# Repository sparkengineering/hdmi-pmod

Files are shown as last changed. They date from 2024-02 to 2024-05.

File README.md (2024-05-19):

# hdmi-pmod





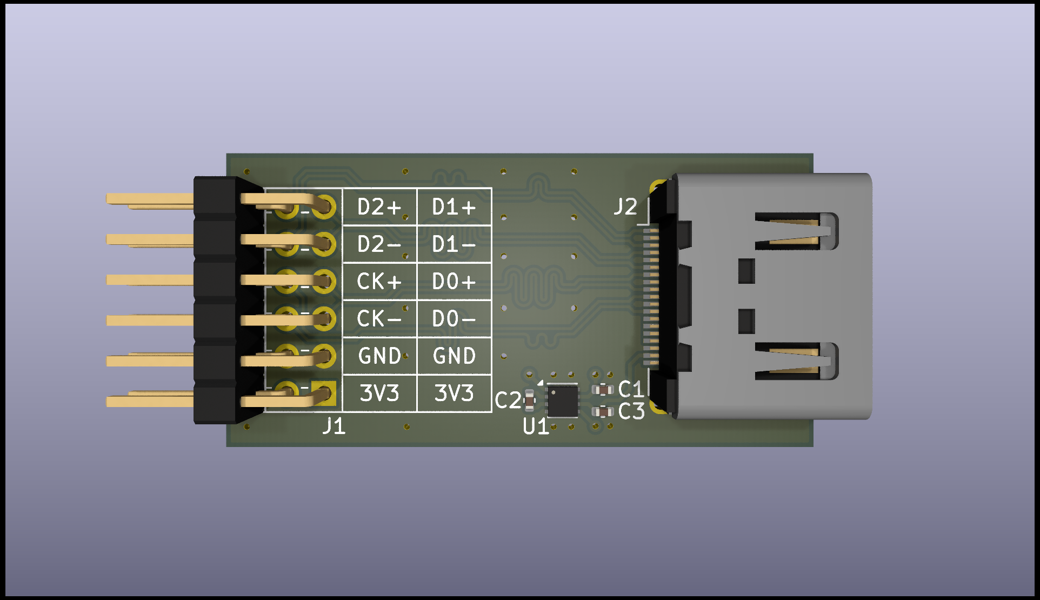
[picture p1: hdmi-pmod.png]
3D render of this HDMI Pmod breakout board


## Description

HDMI type A receptacle to Digilent Pmod™ breakout board.

- Impedance matched & length tuned differential lines
- Includes 3.3V to 5V boost converter (max. 200mA)
- Pinout to match Digilent high-speed Pmod™ e.g. on Arty A7
- Tested with Arty A7 board at 1280x720 @ 60HZ

## Contents

| File | Description |
|---|---|
| [hdmi-pmod.pdf](./hdmi-pmod.pdf) | Schematic in PDF format |
| [hdmi-pmod.csv](./hdmi-pmod.csv) | BOM in CSV format |
| [hdmi-pmod.png](./hdmi-pmod.png) | PCB 3D render |
| | |
| [hdmi-pmod.kicad_pro](./hdmi-pmod.kicad_pro) | KiCad 8.0.2 project |
| [hdmi-pmod.kicad_pcb](./hdmi-pmod.kicad_pcb) | KiCad 8.0.2 PCB |
| [hdmi-pmod.kicad_sch](./hdmi-pmod.kicad_sch) | KiCad 8.0.2 schematic |

## Further Reading

- FPGA display controller with support for VGA, DVI, and HDMI [^1]
- Digital Visual Interface Specification Version 1.0 [^2]
- BML DVI digital video for FPGAs over PMOD [^3]
- fpga4fun.com HDMI [^4]
- Hackaday.io HDMI PMOD [^5]

[^1]: https://github.com/projf/display_controller
[^2]: https://glenwing.github.io/docs/DVI-1.0.pdf
[^3]: https://blackmesalabs.wordpress.com/2017/12/15/bml-hdmi-video-for-fpgas-over-pmod/
[^4]: https://www.fpga4fun.com/HDMI.html
[^5]: https://hackaday.io/project/176327-hdmi-pmod

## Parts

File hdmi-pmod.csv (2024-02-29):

Reference | Value | Footprint | Qty | DNP | MFG | MPN | OC_LCSC | OC_Mouser
C1,C3 | 2.2µF | Capacitor_SMD:C_0402_1005Metric | 2 |  | Murata Electronics | GRM155R61C225KE11D | C88944 | 81-GRM155R61C225KE1D
C2 | 1µF | Capacitor_SMD:C_0402_1005Metric | 1 |  | Murata Electronics | GRM155R61C105KA12D | C77006 | 81-GRM155R61C105KA2D
J1 | Conn_02x06_Odd_Even | hdmi-pmod:PinHeader_2x06_P2.54mm_Horizontal | 1 |  | TE Connectivity | 826634-6 | ~ | 571-826634-6
J2 | HDMI_A | hdmi-pmod:HDMI_A_Molex_208658-1001_Horizontal | 1 |  | Molex | 208658-1001 | ~ | 538-208658-1001
U1 | LM2775DSG | Package_SON:WSON-8-1EP_2x2mm_P0.5mm_EP0.9x1.6mm | 1 |  | Texas Instruments | LM2775DSGT | C2070762 | 595-LM2775DSGT

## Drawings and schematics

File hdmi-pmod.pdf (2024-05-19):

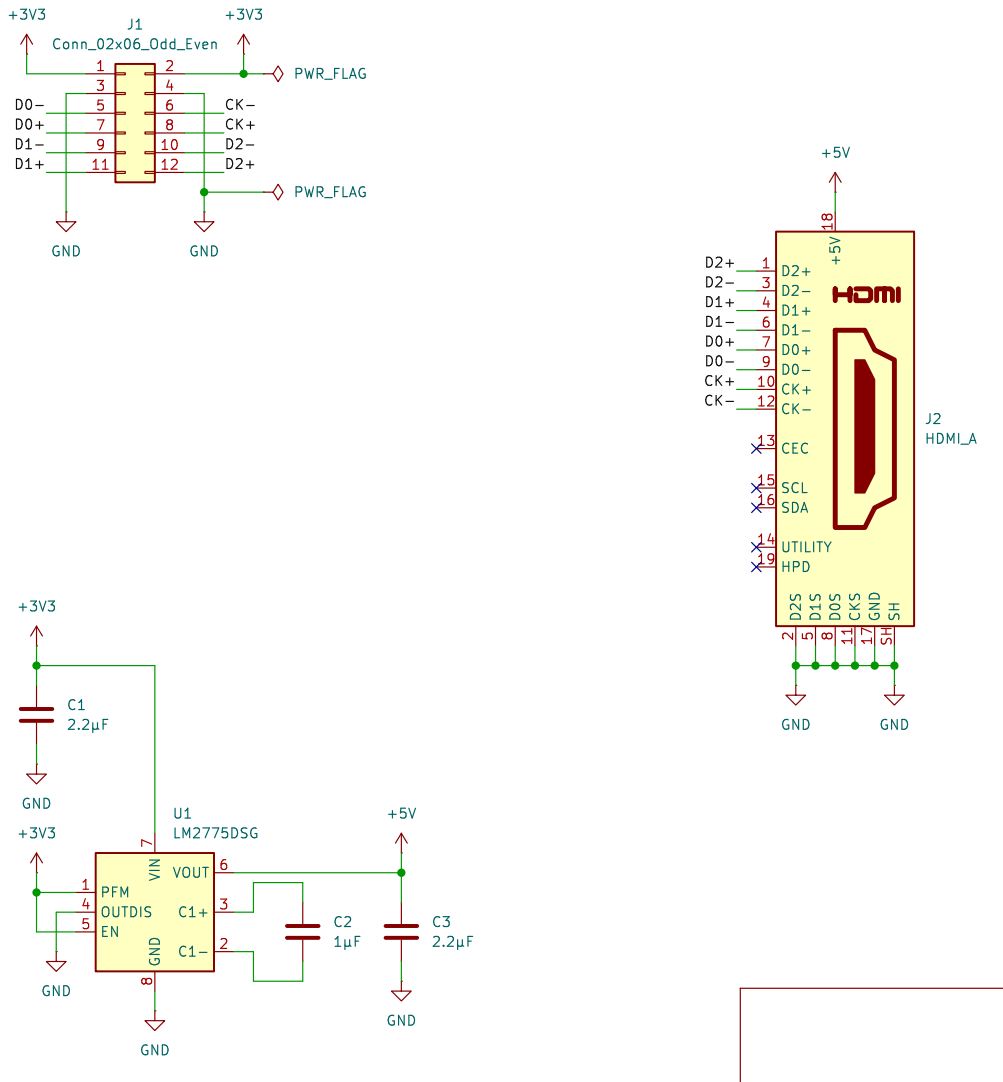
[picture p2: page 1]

Id: 1/1 Title: HDMI Pmod

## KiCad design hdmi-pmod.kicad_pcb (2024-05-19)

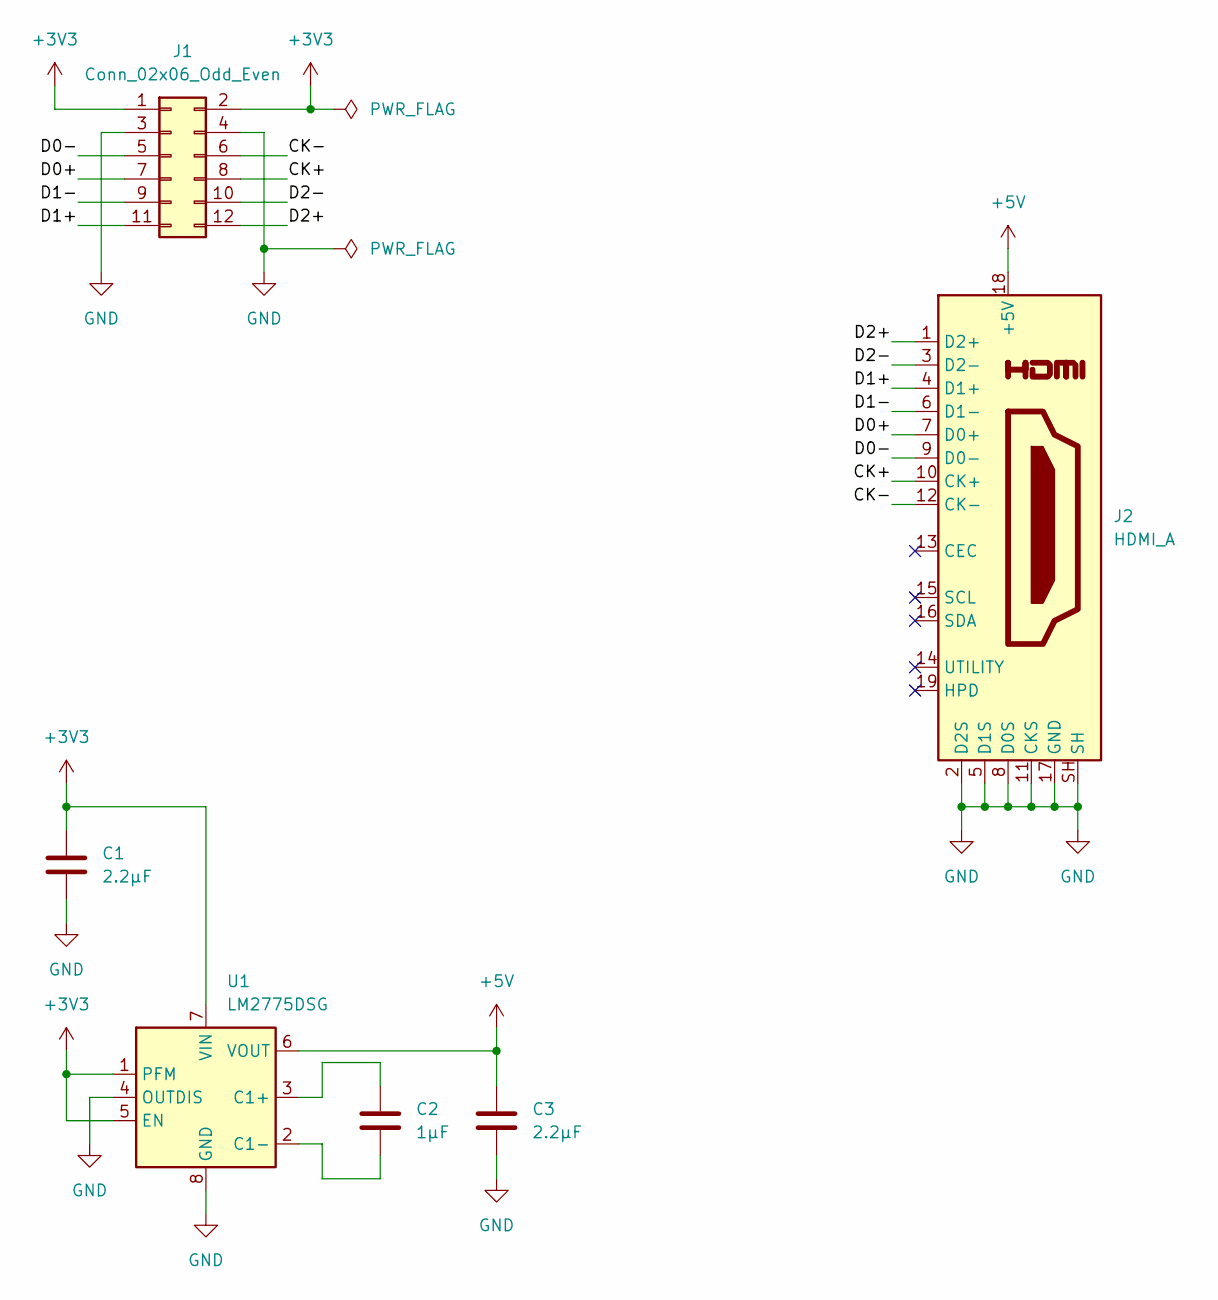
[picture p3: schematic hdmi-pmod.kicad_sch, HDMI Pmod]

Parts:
C1, C3: 2.2µF; C_0402_1005Metric; MPN GRM155R61C225KE11D
C2: 1µF; C_0402_1005Metric; MPN GRM155R61C105KA12D
J1: Conn_02x06_Odd_Even; PinHeader_2x06_P2.54mm_Horizontal; MPN 826634-6
J2: HDMI_A; HDMI_A_Molex_208658-1001_Horizontal; MPN 208658-1001
U1: LM2775DSG; WSON-8-1EP_2x2mm_P0.5mm_EP0.9x1.6mm; MPN LM2775DSGT

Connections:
+3V3: C1.1, J1.1, J1.2, U1.1 (PFM), U1.5 (EN), U1.7 (VIN)
+5V: C3.1, J2.18 (+5V), U1.6 (VOUT)
/CK+: J1.8, J2.10 (CK+)
/CK-: J1.6, J2.12 (CK-)
/D0+: J1.7, J2.7 (D0+)
/D0-: J1.5, J2.9 (D0-)
/D1+: J1.11, J2.4 (D1+)
/D1-: J1.9, J2.6 (D1-)
/D2+: J1.12, J2.1 (D2+)
/D2-: J1.10, J2.3 (D2-)
GND: C1.2, C3.2, J1.3, J1.4, J2.2 (D2S), J2.5 (D1S), J2.8 (D0S), J2.11 (CKS), J2.17 (GND), J2.SH, U1.4 (OUTDIS), U1.8 (GND), U1.9 (GND)
unnamed: C2.1, U1.3 (C1+)
unnamed: C2.2, U1.2 (C1-)

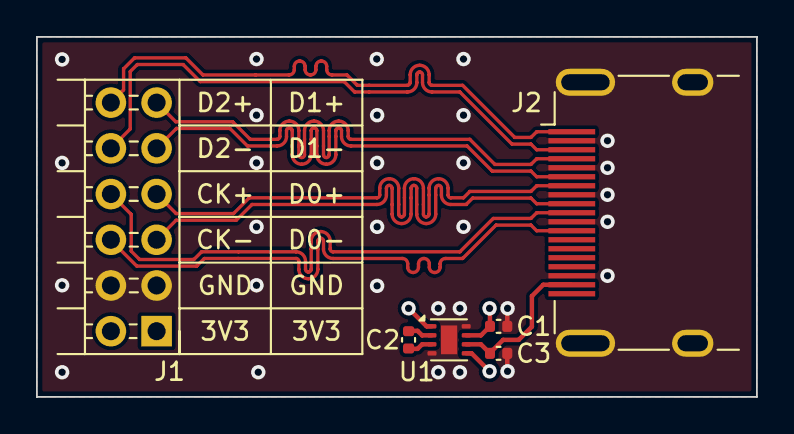
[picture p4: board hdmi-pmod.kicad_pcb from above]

Board: 4 copper layers, 40.0 x 20.0 mm, 6 parts (0 on the bottom side), 13 nets.

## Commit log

2024-03-21 Update symbols, fix ERC
    [hdmi-pmod.kicad_sch]
2024-03-23 Add kicad-action ERC/DRC checks
2024-05-19 Add revision v1.1
    Update symbols, footprints, etc. for KiCad 8.0.2
    Remove custom bridges to remove DRC errors
    Increment revision number
    [hdmi-pmod.kicad_pcb, hdmi-pmod.kicad_sch]
2024-05-19 Bump kicad-action workflow version
2024-05-19 Waive remaining silkscreen DRC violations
